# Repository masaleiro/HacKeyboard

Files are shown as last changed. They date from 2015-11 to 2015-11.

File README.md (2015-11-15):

# HacKeyboard

Open hardware mechanical keyboard, by Mário Saleiro

HacKeyboard is a mechanical keyboard built from scratch using SMK Alps Mount switches from an old Monterey K108 keyboard and Alps compatible keycaps from an old NGS keyboard.

It has several features that are not usually found in commercial keyboards:
- Internal keylogger;
- Macro recording capabilites;
- Internal USB Hub 2.0;
- Internal (hidden) 8GB flash drive;
- Micro USB Port for connecting peripherals;
- Customizable LED colors;
- Customizable LED effects;

The whole build process is documented and available here: http://www.instructables.com/id/HacKeyboard-a-mechanical-keyboard-built-from-scrat/

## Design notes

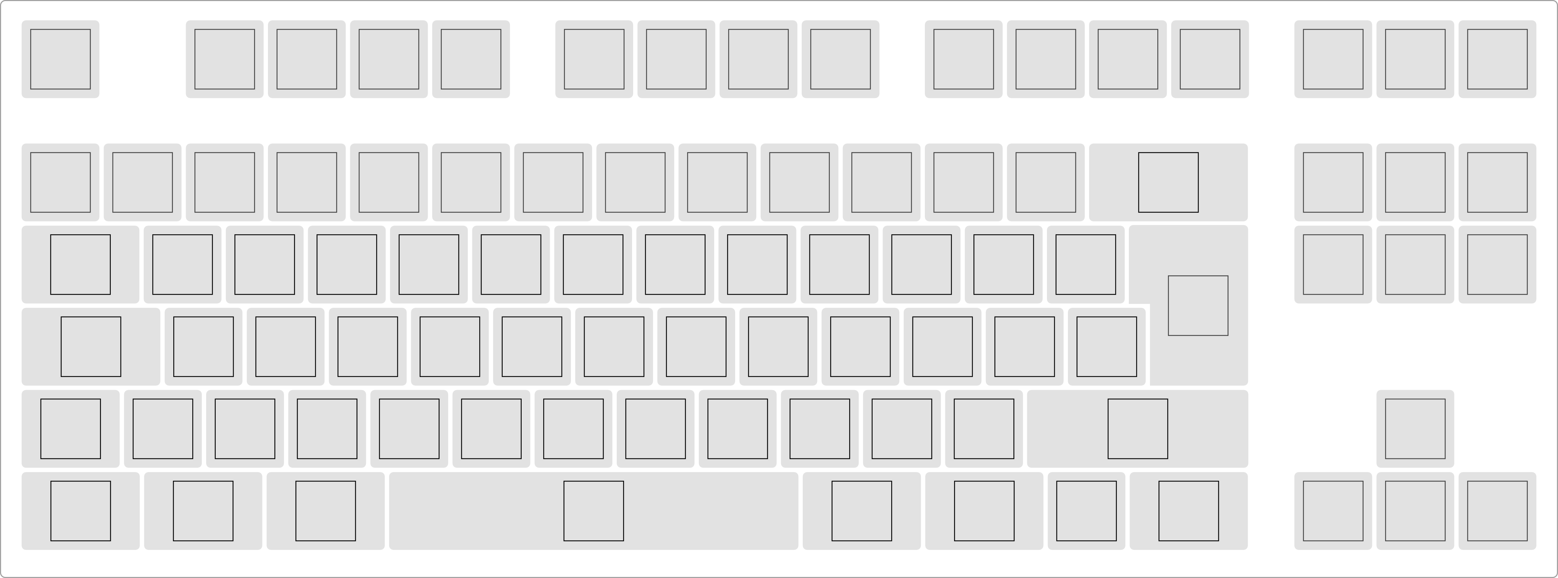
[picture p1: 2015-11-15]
Frame Prototype - Inkscape/rect4722.png

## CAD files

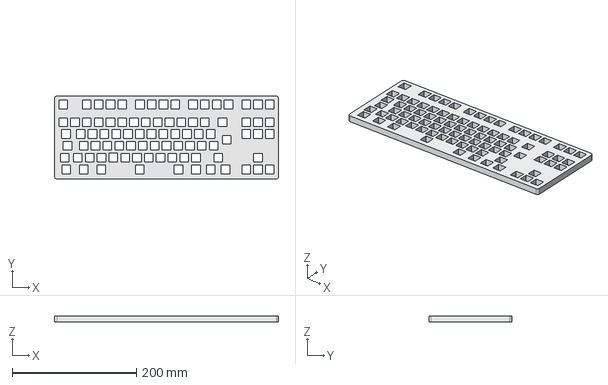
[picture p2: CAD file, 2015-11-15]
Frame - FreeCAD/frame.step
360.5 x 133.7 x 10.0 mm

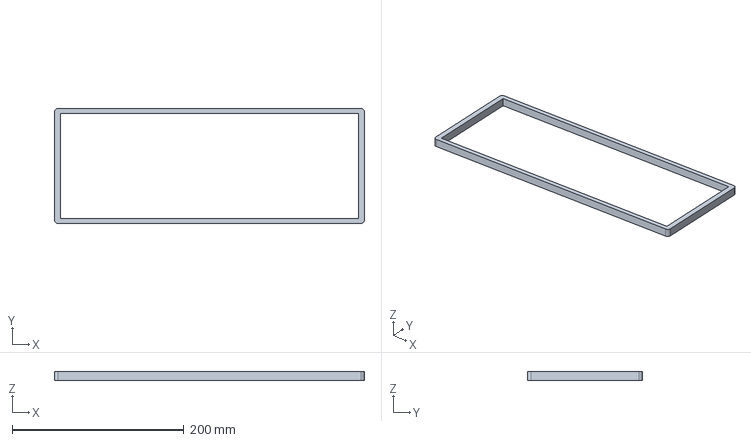
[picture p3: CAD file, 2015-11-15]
Frame - FreeCAD/middle_layer1.step
360.5 x 133.7 x 10.0 mm

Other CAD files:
Machining Files - HeeksCAD/keyboard.iges
Frame - FreeCAD/frame.fcstd
Frame - FreeCAD/middle_layer1.fcstd
Machining Files - HeeksCAD/keyboard.stl

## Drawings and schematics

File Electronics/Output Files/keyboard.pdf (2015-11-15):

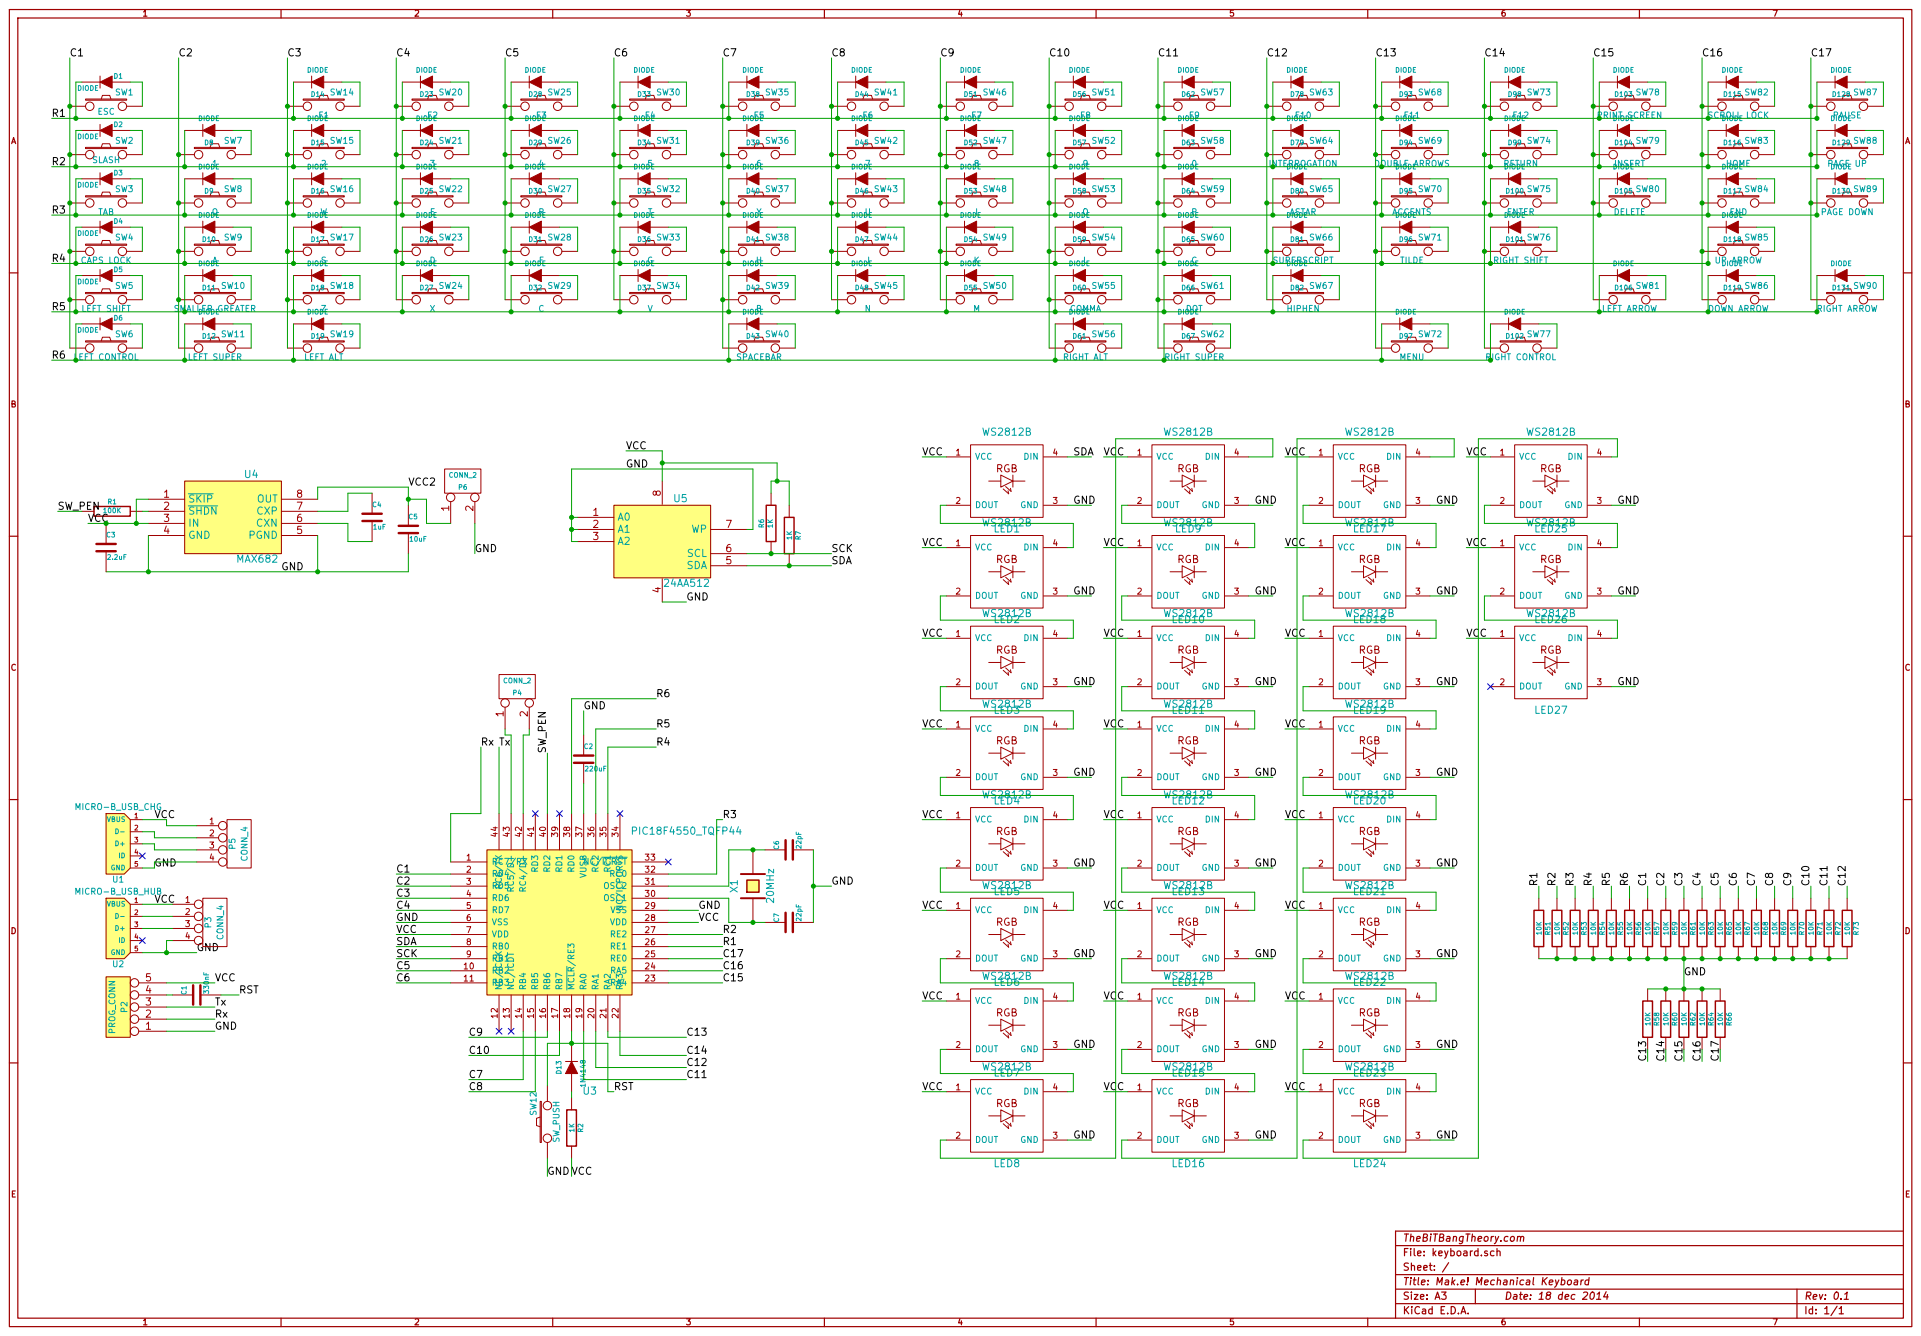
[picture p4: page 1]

D44 DIODE D45 DIODE D46 DIODE D47 DIODE D48 DIODE C8

TheBiTBangTheory.com
File: keyboard.sch
Sheet: /
Title: Mak.e! Mechanical Keyboard

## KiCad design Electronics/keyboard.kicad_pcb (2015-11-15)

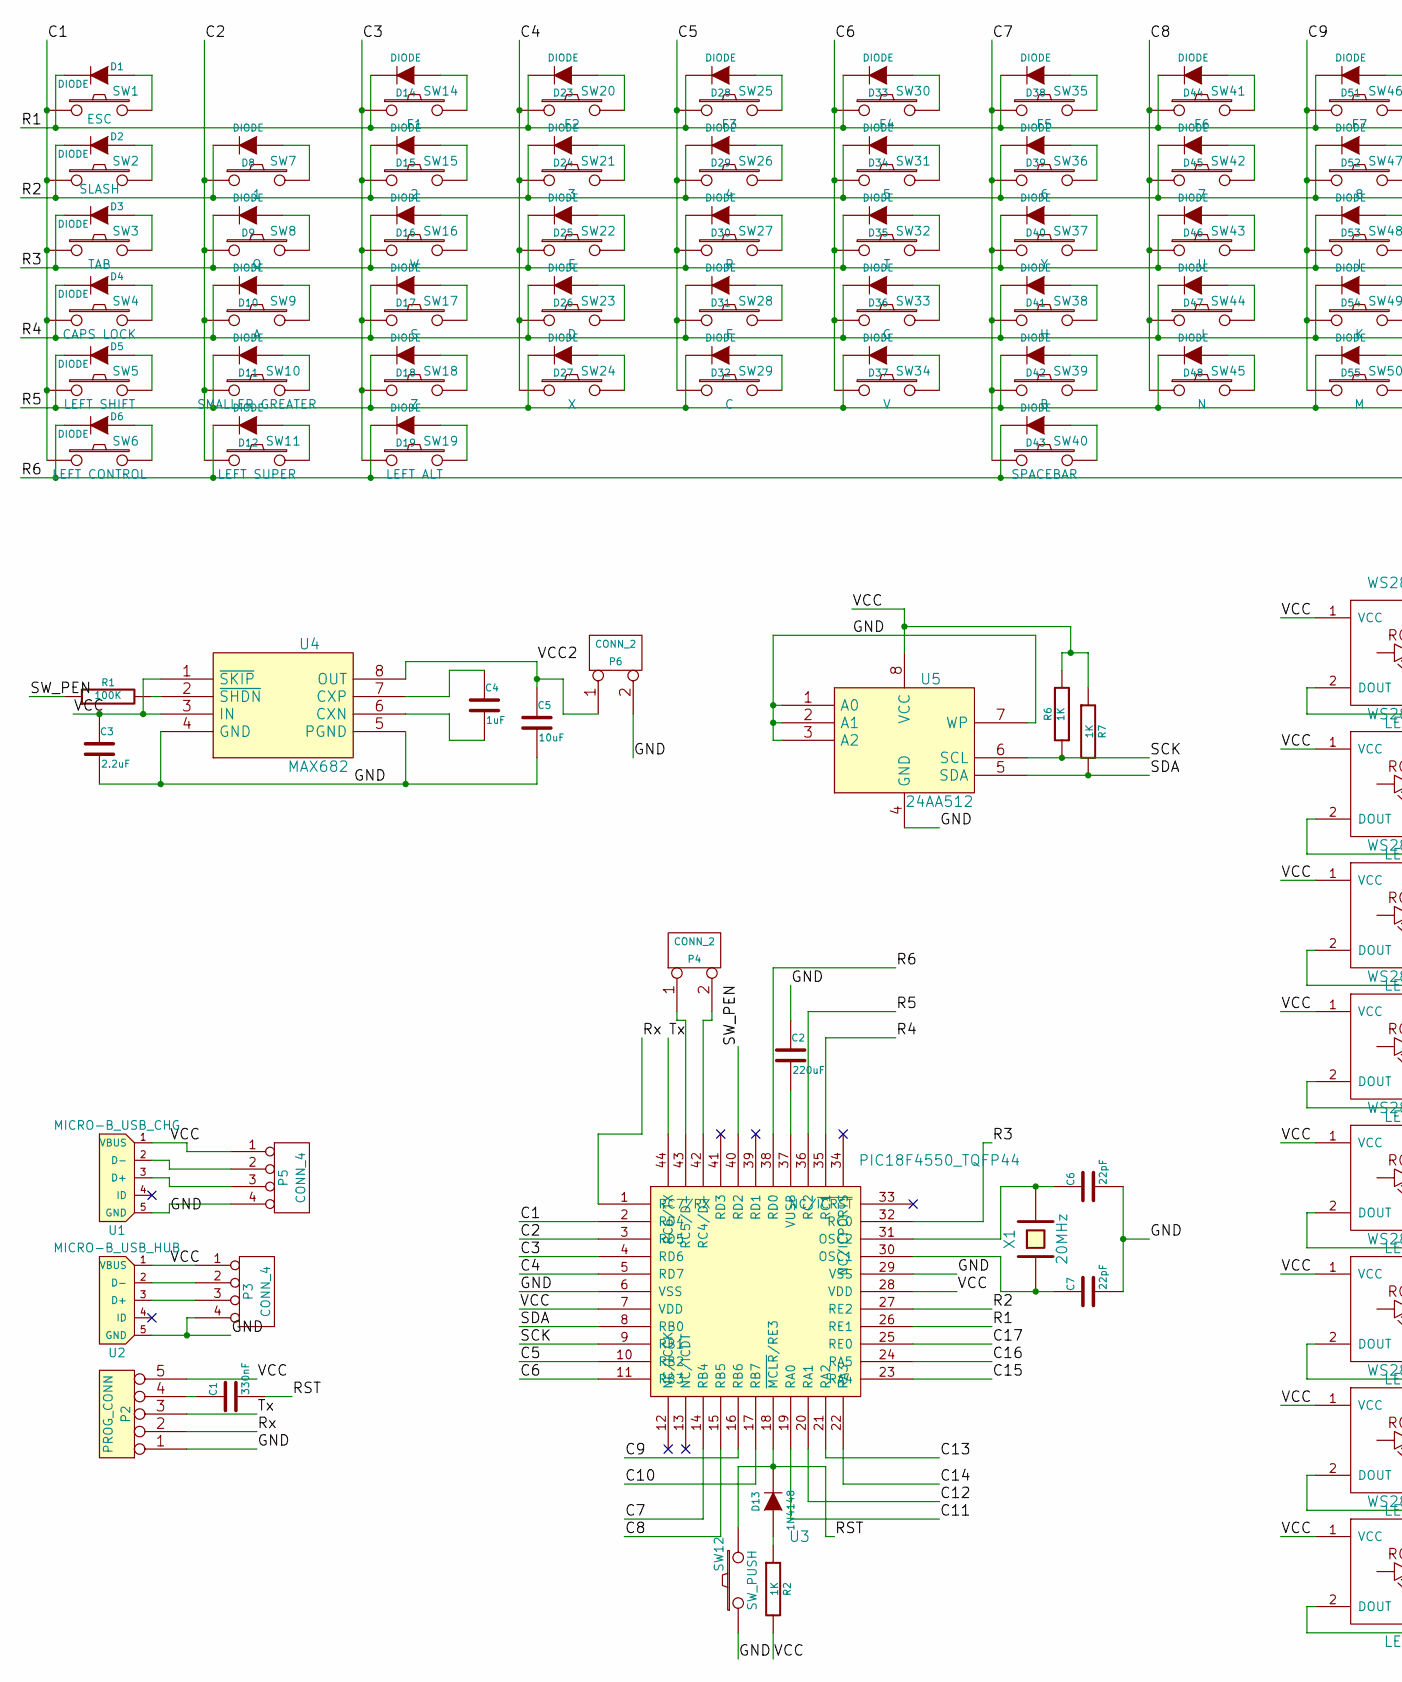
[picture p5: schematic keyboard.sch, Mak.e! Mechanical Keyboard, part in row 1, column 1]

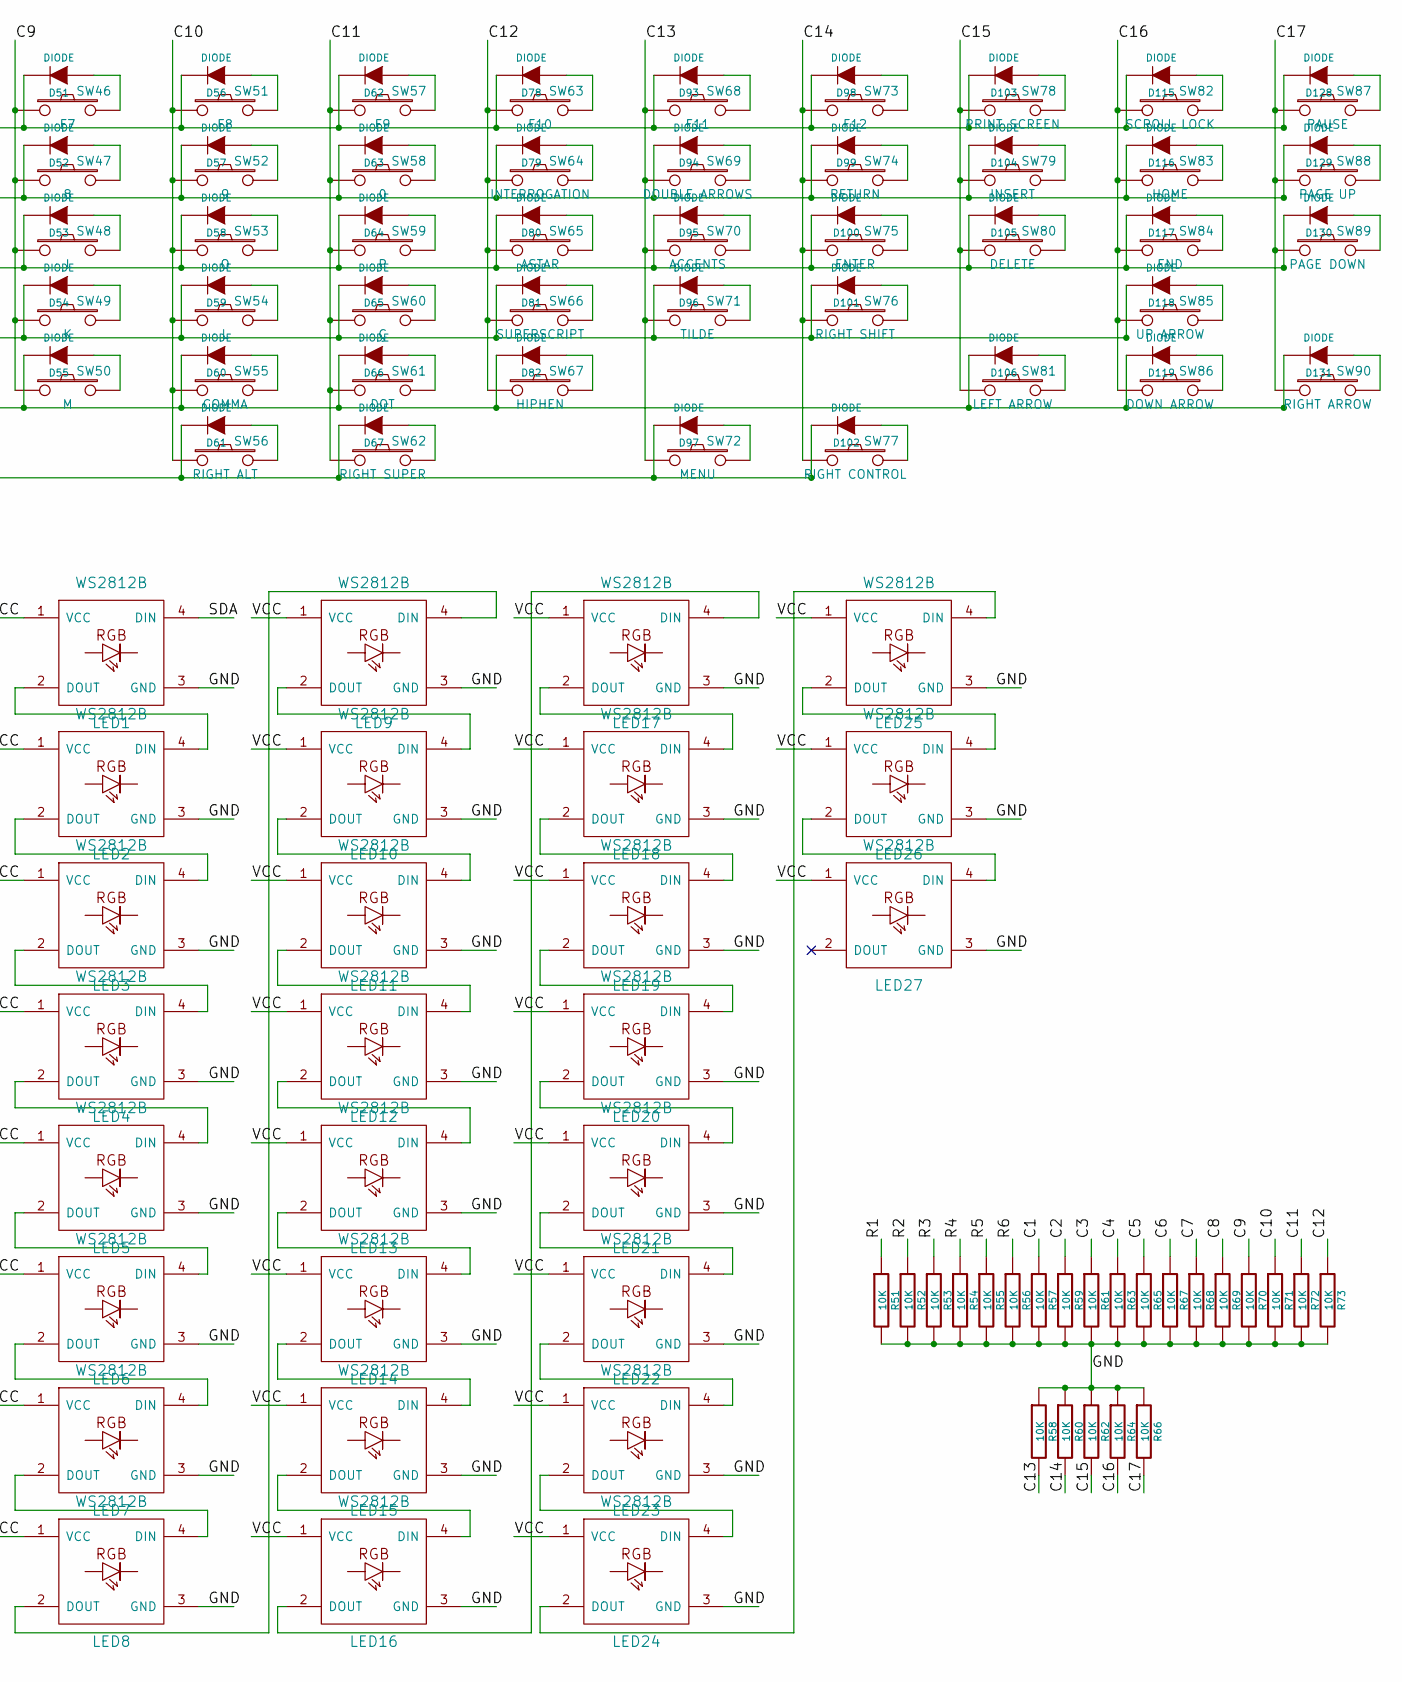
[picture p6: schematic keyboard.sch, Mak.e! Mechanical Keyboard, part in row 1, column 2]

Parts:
C1: 330nF
C2: 220uF
C3: 2.2uF
C4: 1uF
C5: 10uF
C6, C7: 22pF
D1, D2, D3, D4, D5, D6, D8, D9, D10, D11, D12, D14, D15, D16, D17, D18, D19, D23, D24, D25, D26, D27, D28, D29, D30, D31, D32, D33, D34, D35, D36, D37, D38, D39, D40, D41, D42, D43, D44, D45, D46, D47, D48, D51, D52, D53, D54, D55, D56, D57, D58, D59, D60, D61, D62, D63, D64, D65, D66, D67, D78, D79, D80, D81, D82, D93, D94, D95, D96, D97, D98, D99, D100, D101, D102, D103, D104, D105, D106, D115, D116, D117, D118, D119, D128, D129, D130, D131: DIODE
D13: 1N4148
LED1, LED2, LED3, LED4, LED5, LED6, LED7, LED8, LED9, LED10, LED11, LED12, LED13, LED14, LED15, LED16, LED17, LED18, LED19, LED20, LED21, LED22, LED23, LED24, LED25, LED26, LED27: WS2812B
P2: PROG_CONN
P3, P5: CONN_4
P4, P6: CONN_2
R1: 100K
R2, R6, R7: 1K
R51, R52, R53, R54, R55, R56, R57, R58, R59, R60, R61, R62, R63, R64, R65, R66, R67, R68, R69, R70, R71, R72, R73: 10K
SW1: ESC
SW2: SLASH
SW3: TAB
SW4: CAPS LOCK
SW5: LEFT SHIFT
SW6: LEFT CONTROL
SW7: 1
SW8: Q
SW9: A
SW10: SMALLER GREATER
SW11: LEFT SUPER
SW12: SW_PUSH
SW14: F1
SW15: 2
SW16: W
SW17: S
SW18: Z
SW19: LEFT ALT
SW20: F2
SW21: 3
SW22: E
SW23: D
SW24: X
SW25: F3
SW26: 4
SW27: R
SW28: F
SW29: C
SW30: F4
SW31: 5
SW32: T
SW33: G
SW34: V
SW35: F5
SW36: 6
SW37: Y
SW38: H
SW39: B
SW40: SPACEBAR
SW41: F6
SW42: 7
SW43: U
SW44: J
SW45: N
SW46: F7
SW47: 8
SW48: I
SW49: K
SW50: M
SW51: F8
SW52: 9
SW53: O
SW54: L
SW55: COMMA
SW56: RIGHT ALT
SW57: F9
SW58: 0
SW59: P
SW60: Ç
SW61: DOT
SW62: RIGHT SUPER
SW63: F10
SW64: INTERROGATION
SW65: ASTAR
SW66: SUPERSCRIPT
SW67: HIPHEN
SW68: F11
SW69: DOUBLE ARROWS
SW70: ACCENTS
SW71: TILDE
SW72: MENU
SW73: F12
SW74: RETURN
SW75: ENTER
SW76: RIGHT SHIFT
SW77: RIGHT CONTROL
SW78: PRINT SCREEN
SW79: INSERT
SW80: DELETE
SW81: LEFT ARROW
SW82: SCROLL LOCK
SW83: HOME
SW84: END
SW85: UP ARROW
SW86: DOWN ARROW
SW87: PAUSE
SW88: PAGE UP
SW89: PAGE DOWN
SW90: RIGHT ARROW
U1: MICRO-B_USB_CHG
U2: MICRO-B_USB_HUB
U3: PIC18F4550_TQFP44
U4: MAX682
U5: 24AA512
X1: 20MHz

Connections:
/C1: R57.1, SW1.1, SW2.1, SW3.1, SW4.1, SW5.1, SW6.1, U3.2 (RD4)
/C2: R59.1, SW7.1, SW8.1, SW9.1, SW10.1, SW11.1, U3.3 (RD5)
/C3: R61.1, SW14.1, SW15.1, SW16.1, SW17.1, SW18.1, SW19.1, U3.4 (RD6)
/C4: R63.1, SW20.1, SW21.1, SW22.1, SW23.1, SW24.1, U3.5 (RD7)
/C5: R65.1, SW25.1, SW26.1, SW27.1, SW28.1, SW29.1, U3.10 (RB2)
/C6: R67.1, SW30.1, SW31.1, SW32.1, SW33.1, SW34.1, U3.11 (RB3)
/C7: R68.1, SW35.1, SW36.1, SW37.1, SW38.1, SW39.1, SW40.1, U3.14 (RB4)
/C8: R69.1, SW41.1, SW42.1, SW43.1, SW44.1, SW45.1, U3.15 (RB5)
/C9: R70.1, SW46.1, SW47.1, SW48.1, SW49.1, SW50.1, U3.16 (RB6)
/C10: R71.1, SW51.1, SW52.1, SW53.1, SW54.1, SW55.1, SW56.1, U3.17 (RB7)
/C11: R72.1, SW57.1, SW58.1, SW59.1, SW60.1, SW61.1, SW62.1, U3.19 (RA0)
/C12: R73.1, SW63.1, SW64.1, SW65.1, SW66.1, SW67.1, U3.20 (RA1)
/C13: R58.2, SW68.1, SW69.1, SW70.1, SW71.1, SW72.1, U3.21 (RA2)
/C14: R60.2, SW73.1, SW74.1, SW75.1, SW76.1, SW77.1, U3.22 (RA3)
/C15: R62.2, SW78.1, SW79.1, SW80.1, SW81.1, U3.23 (RA4)
/C16: R64.2, SW82.1, SW83.1, SW84.1, SW85.1, SW86.1, U3.24 (RA5)
/C17: R66.2, SW87.1, SW88.1, SW89.1, SW90.1, U3.25 (RE0)
/GND: C2.1, C3.2, C5.2, C6.2, C7.2, LED1.3 (GND), LED2.3 (GND), LED3.3 (GND), LED4.3 (GND), LED5.3 (GND), LED6.3 (GND), LED7.3 (GND), LED8.3 (GND), LED9.3 (GND), LED10.3 (GND), LED11.3 (GND), LED12.3 (GND), LED13.3 (GND), LED14.3 (GND), LED15.3 (GND), LED16.3 (GND), LED17.3 (GND), LED18.3 (GND), LED19.3 (GND), LED20.3 (GND), LED21.3 (GND), LED22.3 (GND), LED23.3 (GND), LED24.3 (GND), LED25.3 (GND), LED26.3 (GND), LED27.3 (GND), P2.1, P3.4, P5.4, P6.2 (PM), R51.2, R52.2, R53.2, R54.2, R55.2, R56.2, R57.2, R58.1, R59.2, R60.1, R61.2, R62.1, R63.2, R64.1, R65.2, R66.1, R67.2, R68.2, R69.2, R70.2, R71.2, R72.2, R73.2, SW12.1, U1.5 (GND), U2.5 (GND), U3.6 (VSS), U3.29 (VSS), U4.4 (GND), U4.5 (PGND), U5.1 (A0), U5.2 (A1), U5.3 (A2), U5.4 (GND), U5.7 (WP)
/R1: D1.2 (K), D14.2 (K), D23.2 (K), D28.2 (K), D33.2 (K), D38.2 (K), D44.2 (K), D51.2 (K), D56.2 (K), D62.2 (K), D78.2 (K), D93.2 (K), D98.2 (K), D103.2 (K), D115.2 (K), D128.2 (K), R51.1, U3.26 (RE1)
/R2: D2.2 (K), D8.2 (K), D15.2 (K), D24.2 (K), D29.2 (K), D34.2 (K), D39.2 (K), D45.2 (K), D52.2 (K), D57.2 (K), D63.2 (K), D79.2 (K), D94.2 (K), D99.2 (K), D104.2 (K), D116.2 (K), D129.2 (K), R52.1, U3.27 (RE2)
/R3: D3.2 (K), D9.2 (K), D16.2 (K), D25.2 (K), D30.2 (K), D35.2 (K), D40.2 (K), D46.2 (K), D53.2 (K), D58.2 (K), D64.2 (K), D80.2 (K), D95.2 (K), D100.2 (K), D105.2 (K), D117.2 (K), D130.2 (K), R53.1, U3.32 (RC0)
/R4: D4.2 (K), D10.2 (K), D17.2 (K), D26.2 (K), D31.2 (K), D36.2 (K), D41.2 (K), D47.2 (K), D54.2 (K), D59.2 (K), D65.2 (K), D81.2 (K), D96.2 (K), D101.2 (K), D118.2 (K), R54.1, U3.35 (RC1)
/R5: D5.2 (K), D11.2 (K), D18.2 (K), D27.2 (K), D32.2 (K), D37.2 (K), D42.2 (K), D48.2 (K), D55.2 (K), D60.2 (K), D66.2 (K), D82.2 (K), D106.2 (K), D119.2 (K), D131.2 (K), R55.1, U3.36 (RC2)
/R6: D6.2 (K), D12.2 (K), D19.2 (K), D43.2 (K), D61.2 (K), D67.2 (K), D97.2 (K), D102.2 (K), R56.1, U3.38 (RD0)
/RST: C1.2, D13.2 (K), SW12.2, U3.18 (~MCLR~/RE3)
/Rx: P2.2, U3.1 (RC7/RX)
/SCK: R6.1, U3.9 (RB1), U5.6 (SCL)
/SDA: LED1.4 (DIN), R7.2, U3.8 (RB0), U5.5 (SDA)
/SW_PEN: R1.1, U3.40 (RD2)
/Tx: P2.3, U3.44 (RC6/TX)
/VCC: C3.1, LED1.1 (VCC), LED2.1 (VCC), LED3.1 (VCC), LED4.1 (VCC), LED5.1 (VCC), LED6.1 (VCC), LED7.1 (VCC), LED8.1 (VCC), LED9.1 (VCC), LED10.1 (VCC), LED11.1 (VCC), LED12.1 (VCC), LED13.1 (VCC), LED14.1 (VCC), LED15.1 (VCC), LED16.1 (VCC), LED17.1 (VCC), LED18.1 (VCC), LED19.1 (VCC), LED20.1 (VCC), LED21.1 (VCC), LED22.1 (VCC), LED23.1 (VCC), LED24.1 (VCC), LED25.1 (VCC), LED26.1 (VCC), LED27.1 (VCC), P2.5, P3.1, P5.1, R2.2, R6.2, R7.1, U1.1 (VBUS), U2.1 (VBUS), U3.7 (VDD), U3.28 (VDD), U4.1 (~SKIP), U4.3 (IN), U5.8 (VCC)
/VCC2: C5.1, P6.1, U4.8 (OUT)
unnamed: C1.1, P2.4
unnamed: C2.2, U3.37 (VUSB)
unnamed: D115.1 (A), SW82.2
unnamed: D130.1 (A), SW89.2
unnamed: D129.1 (A), SW88.2
unnamed: D128.1 (A), SW87.2
unnamed: D131.1 (A), SW90.2
unnamed: D116.1 (A), SW83.2
unnamed: D117.1 (A), SW84.2
unnamed: D118.1 (A), SW85.2
unnamed: D119.1 (A), SW86.2
unnamed: D13.1 (A), R2.1
unnamed: P4.2 (PM), U3.42 (RC4/D+)
unnamed: P4.1, U3.43 (RC5/D+)
unnamed: P5.3, U1.3 (D+)
unnamed: P5.2, U1.2 (D-)
unnamed: P3.3, U2.3 (D+)
unnamed: P3.2, U2.2 (D-)
unnamed: D61.1 (A), SW56.2
unnamed: D60.1 (A), SW55.2
unnamed: D67.1 (A), SW62.2
unnamed: D66.1 (A), SW61.2
unnamed: D65.1 (A), SW60.2
unnamed: D64.1 (A), SW59.2
unnamed: D63.1 (A), SW58.2
unnamed: D62.1 (A), SW57.2
unnamed: D46.1 (A), SW43.2
unnamed: D44.1 (A), SW41.2
unnamed: D45.1 (A), SW42.2
unnamed: D47.1 (A), SW44.2
unnamed: D48.1 (A), SW45.2
unnamed: D53.1 (A), SW48.2
unnamed: D59.1 (A), SW54.2
unnamed: D58.1 (A), SW53.2
unnamed: D57.1 (A), SW52.2
unnamed: D56.1 (A), SW51.2
unnamed: D55.1 (A), SW50.2
unnamed: D54.1 (A), SW49.2
unnamed: D52.1 (A), SW47.2
unnamed: D51.1 (A), SW46.2
unnamed: D102.1 (A), SW77.2
unnamed: D101.1 (A), SW76.2
unnamed: D100.1 (A), SW75.2
unnamed: D99.1 (A), SW74.2
unnamed: D98.1 (A), SW73.2
unnamed: D103.1 (A), SW78.2
unnamed: D106.1 (A), SW81.2
unnamed: D105.1 (A), SW80.2
unnamed: D104.1 (A), SW79.2
unnamed: D82.1 (A), SW67.2
unnamed: D81.1 (A), SW66.2
unnamed: D80.1 (A), SW65.2
unnamed: D79.1 (A), SW64.2
unnamed: D78.1 (A), SW63.2
unnamed: D97.1 (A), SW72.2
unnamed: D93.1 (A), SW68.2
unnamed: D94.1 (A), SW69.2
unnamed: D95.1 (A), SW70.2
unnamed: D96.1 (A), SW71.2
unnamed: LED21.2 (DOUT), LED22.4 (DIN)
unnamed: LED22.2 (DOUT), LED23.4 (DIN)
unnamed: LED16.2 (DOUT), LED17.4 (DIN)
unnamed: LED24.2 (DOUT), LED25.4 (DIN)
unnamed: LED23.2 (DOUT), LED24.4 (DIN)
unnamed: LED20.2 (DOUT), LED21.4 (DIN)
unnamed: LED19.2 (DOUT), LED20.4 (DIN)
unnamed: LED17.2 (DOUT), LED18.4 (DIN)
unnamed: LED18.2 (DOUT), LED19.4 (DIN)
unnamed: C4.1, U4.7 (CXP)
unnamed: C4.2, U4.6 (CXN)
unnamed: R1.2, U4.2 (~SHDN)
unnamed: LED25.2 (DOUT), LED26.4 (DIN)
unnamed: LED26.2 (DOUT), LED27.4 (DIN)
unnamed: LED4.2 (DOUT), LED5.4 (DIN)
unnamed: LED6.2 (DOUT), LED7.4 (DIN)
unnamed: LED5.2 (DOUT), LED6.4 (DIN)
unnamed: LED7.2 (DOUT), LED8.4 (DIN)
unnamed: LED2.2 (DOUT), LED3.4 (DIN)
unnamed: LED3.2 (DOUT), LED4.4 (DIN)
unnamed: LED1.2 (DOUT), LED2.4 (DIN)
unnamed: LED14.2 (DOUT), LED15.4 (DIN)
unnamed: LED13.2 (DOUT), LED14.4 (DIN)
unnamed: LED8.2 (DOUT), LED9.4 (DIN)
unnamed: LED15.2 (DOUT), LED16.4 (DIN)
unnamed: LED12.2 (DOUT), LED13.4 (DIN)
unnamed: LED11.2 (DOUT), LED12.4 (DIN)
unnamed: LED10.2 (DOUT), LED11.4 (DIN)
unnamed: LED9.2 (DOUT), LED10.4 (DIN)
unnamed: D43.1 (A), SW40.2
unnamed: D42.1 (A), SW39.2
unnamed: D41.1 (A), SW38.2
unnamed: D27.1 (A), SW24.2
unnamed: D26.1 (A), SW23.2
unnamed: D25.1 (A), SW22.2
unnamed: D24.1 (A), SW21.2
unnamed: D23.1 (A), SW20.2
unnamed: D19.1 (A), SW19.2
unnamed: D18.1 (A), SW18.2
unnamed: D17.1 (A), SW17.2
unnamed: D16.1 (A), SW16.2
unnamed: D15.1 (A), SW15.2
unnamed: D39.1 (A), SW36.2
unnamed: D38.1 (A), SW35.2
unnamed: D34.1 (A), SW31.2
unnamed: D32.1 (A), SW29.2
unnamed: D30.1 (A), SW27.2
unnamed: D29.1 (A), SW26.2
unnamed: D28.1 (A), SW25.2
unnamed: C6.1, U3.31 (OSC2), X1.2
unnamed: C7.1, U3.30 (OSC1), X1.1
unnamed: D40.1 (A), SW37.2
unnamed: D37.1 (A), SW34.2
unnamed: D36.1 (A), SW33.2
unnamed: D35.1 (A), SW32.2
unnamed: D31.1 (A), SW28.2
unnamed: D33.1 (A), SW30.2
unnamed: D8.1 (A), SW7.2
unnamed: D14.1 (A), SW14.2
unnamed: D12.1 (A), SW11.2
unnamed: D11.1 (A), SW10.2
unnamed: D10.1 (A), SW9.2
unnamed: D9.1 (A), SW8.2
unnamed: D6.1 (A), SW6.2
unnamed: D1.1 (A), SW1.2
unnamed: D5.1 (A), SW5.2
unnamed: D4.1 (A), SW4.2
unnamed: D3.1 (A), SW3.2
unnamed: D2.1 (A), SW2.2

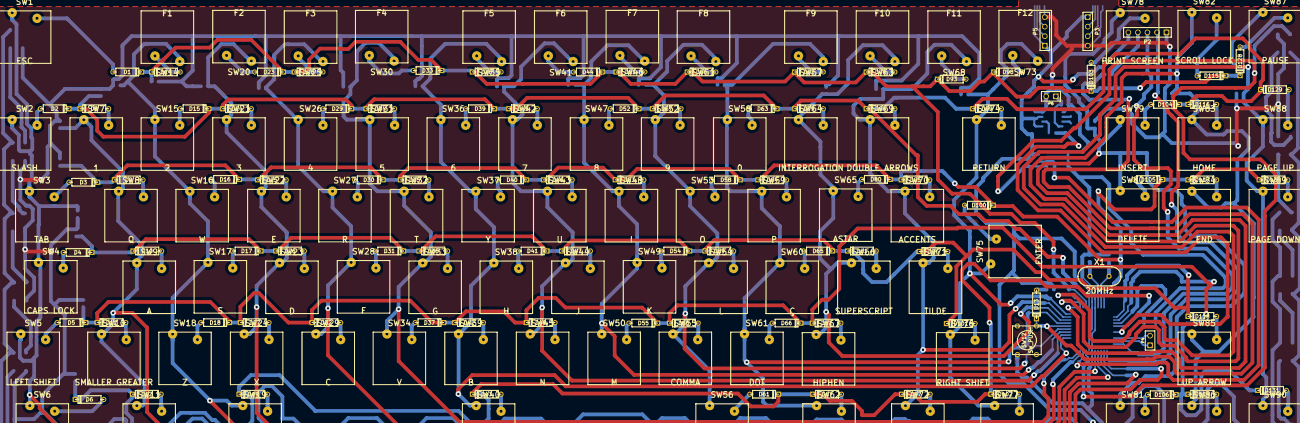
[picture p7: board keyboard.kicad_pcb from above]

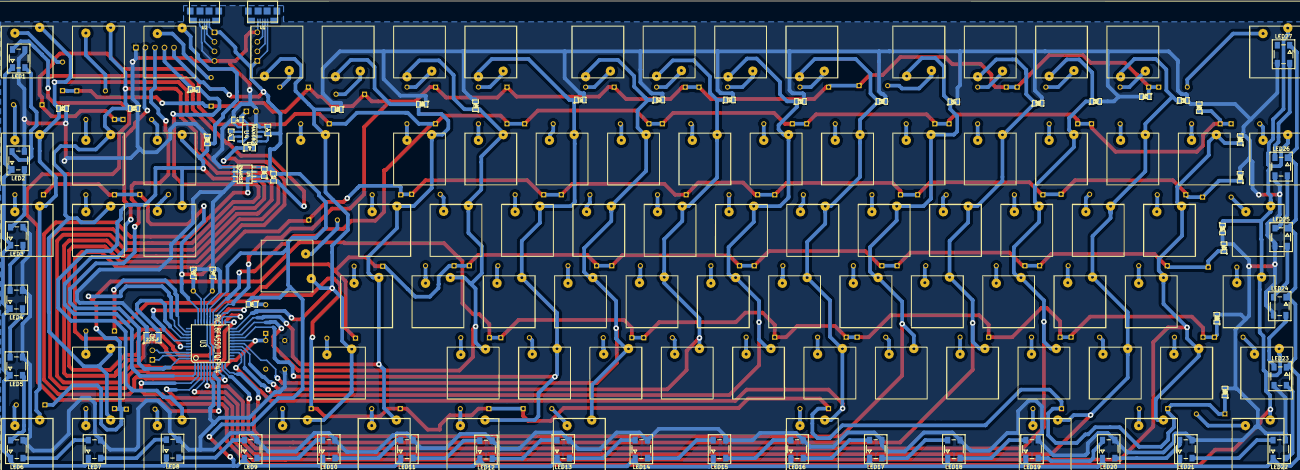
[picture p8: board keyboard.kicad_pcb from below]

Board: 2 copper layers, 250 parts (66 on the bottom side), 160 nets.
